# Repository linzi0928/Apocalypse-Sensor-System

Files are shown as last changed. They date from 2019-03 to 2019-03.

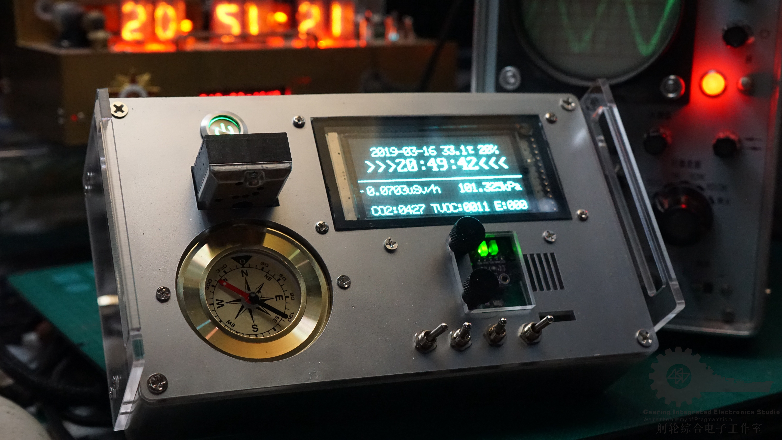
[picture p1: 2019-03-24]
成品照片.JPG

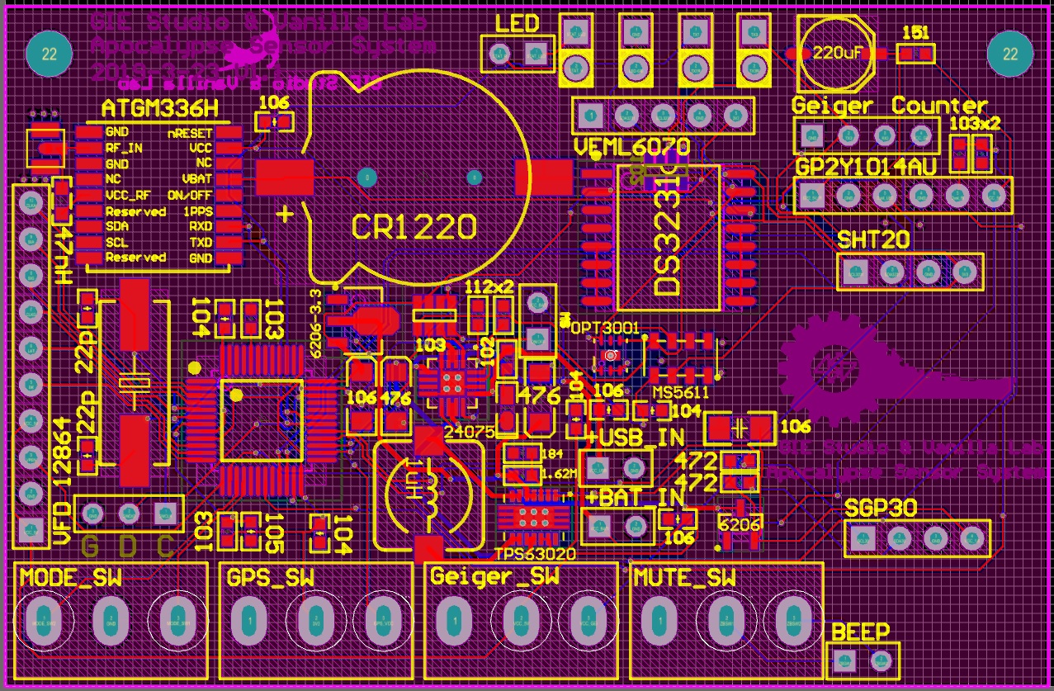
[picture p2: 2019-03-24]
PCB截图.jpg

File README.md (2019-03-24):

舸轮综合电子工作室(GIE工作室)        出品
Gearing Interated Electronics Studio

末世生存预警系统

显示方案：
VFD12864，真空荧光点阵显示屏

硬件方案：
核心控制器STM32F103CBT6
盖革计数器（核辐射计量）整体方案，通过串口3中断接收数据包
GPS(经纬度、海拔、速度、对时):ATGM336H，北斗、GPS和格洛纳斯三模，通过串口1的DMA接收数据包
传感器与芯片方案：
温湿度计SHT20
精准气压计:MS5611（未调通）
照度传感器:OPT3001
紫外线强度传感器:VEML6070
粉尘传感器:GP2Y1014AU
计时芯片:DS3231
上述传感器全部并联在一个IIC总线上。
CO2、TVOC、H2、挥发酒精传感器:SGP30，由于要求1.8V电平和供电，单独使用一个IIC接口

BQ24195是调试阶段使用过然后废弃了，在程序中没有实质性作用，仅做驱动程序参考，现充电芯片为BQ24075，配合TPS63020升压和6206-3.3的LDO

软件方案：
HARDWARE文件夹是各个硬件模块的驱动代码。
USER文件夹中，main.c是主函数所在文件，VFD_Display是将输入数据展现在屏幕上的显示代码，也就是具体界面所在文件
i2c.c是主传感器的IIC总线的驱动代码，myiic.c是紫外线传感器的IIC驱动代码，虽然紫外线传感器与其他传感器公用一
个IIC总线，但是无论如何都无法用主传感器的IIC调通所以单独列出了一个.c文件。
SGP30文件夹中是SGP官方提供的SGP30驱动代码，语法非常复杂，编译器需开启C99模式编译否则会出错。

加群：714483620开源资料汇总
关注B站UP主：GIE工作室 获得更多视频资源
本资料对应的b站视频https://www.bilibili.com/video/av46640142

本开源资料仍需较为专业的技术水平，GIE工作室恕不提供本资料以及QQ群以外任何单独的技术支持
硬件、软件上均可能有未能发现的bug，对于本开源资料的使用可能造成的损失GIE工作室不负任何责任。

2019-3-21第一版
版权所有 禁止用于任何商业用途！
注：程序中DS3231、SGP30、SHT20、VEML6070相关驱动文件来自互联网

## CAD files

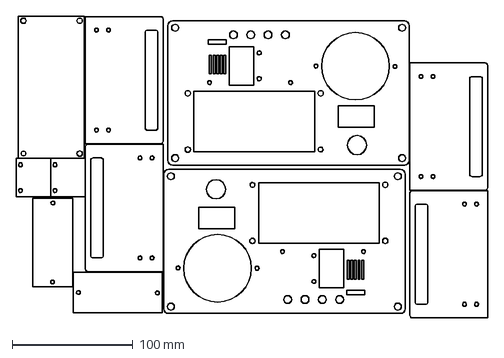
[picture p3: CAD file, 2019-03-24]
外壳开孔（单位2）.dxf
390.5 x 250.0 mm

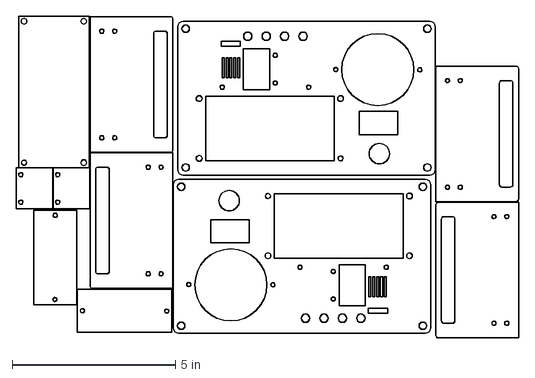
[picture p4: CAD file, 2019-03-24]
外壳开孔（单位1）.dxf
15.4 x 9.84 in

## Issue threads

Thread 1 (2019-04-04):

Software code

ww9980, 2019-04-04:
Hi 我是从B站来的，感谢分享，很喜欢！

在Readme中提到了user文件夹下软件代码，但是似乎并不包含在此处，请问可否上传谢谢！

PS，由于身处国外无法接收绑定了国内手机号的QQ登陆要的验证码所以没法加群，特此。

谢谢,
9980

linzi0928, 2019-06-04:
谢谢提醒，刚刚已经上传

linzi0928, 2019-06-04:
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

谢谢提醒，刚已经上传，不知是否还需要？

ww9980, 2019-09-23:
Great! 非常感谢。请问是否有QQ以外的联系方式？

Closed 2019-09-23.
